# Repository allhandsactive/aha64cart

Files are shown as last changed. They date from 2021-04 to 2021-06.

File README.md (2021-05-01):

## Simple64Cart: AHA Edition ##

This is a modified version of [Simple64Cart](https://github.com/go4retro/Simple64Cart) with the following changes.
* Moved ROM socket slightly to the left so it no longer is pushing up against the board edge
* Allow the use of 16k cart images.
* Allow select one of four 16k banks in the 64k ROM by changing A14 and A15 values via jumpers.

### Jumper Settings ###

##### A14/A15 #####

Jumpers A14 and A15  allow selecting one of four banks in the 64k ROM. This will allow you to program up to four ROM images in an select which one you wish to boot when the computer starts up.

| Memory | A14 | A15 |
| ---|---|---|
|0x0000-0x3fff| closed | closed |
|0x4000-0x7fff| open | closed |
|0x8000-0xbfff| closed | open |
|0xC000-0xffff| open | open |

##### EXROM/GAME #####

These two jumpers /EXROM and /GAME control which memory mapping the C64 uses when mapping your ROM into memory.

There are 3 types of cartridges, 8k, 16k and Ultimax (16k). The two different 16k mappings place the upper 8k at different locations in memory. The main 16k mode will place it at 0xA000 overwriting the basic ROM and Ultimax mode will place it at 0xE000 overwriting the kernel ROM. The lower 8k is always mapped into 0x8000.

The Ultimax mapping is for compatibility with the Japanese Commodore "MAX" computers.

| Mapping | /GAME  | /EXROM |
|---|---|---|
|  None | open | open |
| 8k  (0x8000-0x9 fff) | open | closed |
| 16k (Ultimax) (0x8000-0x9fff),(0xe000-0xffff) | closed | open |
| 16k (0x8000-0x9fff),(0xa000-0xbfff) | closed | closed |

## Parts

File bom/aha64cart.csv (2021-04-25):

Query | Qty | Manufacturer | MPN | Octopart URL | Part Description | Description | Schematic Reference | Total Qty (@ Batch Size: 10) | SKU | Packaging | Unit Price (@ Batch Size: 10) | Notes
CF14JT10K0 | 3 | Stackpole Electronics | CF14JT10K0 | https://octopart.com/cf14jt10k0-stackpole+electronics-19205381 | Res Carbon Film 10K Ohm 5% 0.25W(1/4W) -500ppm/ to 0ppm/ Conformal Coated AXL T/R |  | R1, R2, R3 | 30 | CF14JT10K0CT-ND | Cut Tape | 0.0264
C315C104M5U5TA7301 | 1 | KEMET | C315C104M5U5TA7301 | https://octopart.com/c315c104m5u5ta7301-kemet-20253274 | Cap Ceramic 0.1uF 50V Z5U 20% Radial 2.54mm 85 C T/R |  | C1 | 10 | 399-14010-1-ND | Cut Tape | 0.157
1-2199299-2 | 1 | TE Connectivity | 1-2199299-2 | https://octopart.com/1-2199299-2-te+connectivity-34997809 | 28 Position Dual Wipe Ladder Style DIP IC Socket 0.6" Wide 0.1" Pitch | Intended to work with 27SF512 chip. Paid $1.16/chip via ebay. | U1 | 10 | A120354-ND | Tube | 0.718
68000-402 | 2 | Amphenol ICC / FCI | 68000-402 | https://octopart.com/68000-402-amphenol+icc+%2F+fci-46503223 | Conn Unshrouded Header HDR 2 POS 2.54mm Solder ST Top Entry Thru-Hole BergStik® Bulk |  | A14,A15 | 20 | 609-68000-402-ND | Bulk | 0.119
QPC02SXGN-RC | 3 | Sullins | QPC02SXGN-RC | https://octopart.com/qpc02sxgn-rc-sullins-19878795 | 2 Position 2.54 mm Centerline Single Circuit Open Top Jumper |  | J1, J2, J3 | 30 | S9337-ND | Bag | 0.044
1N4148FS-ND | 2 | ON Semiconductor | 1N4148 | https://octopart.com/1n4148-on+semiconductor-6807167 | 1N4148 Series 500 mW 100 V Max Reverse Voltage 200 mA Small Signal Diode -DO-35 |  | D1, D2 | 20 | 1N4148FS-ND | Bulk | 0.068
67997-404HLF | 1 | Amphenol ICC / FCI | 67997-404HLF | https://octopart.com/67997-404hlf-amphenol+icc+%2F+fci-90333671 | Conn Unshrouded Header HDR 4 POS 2.54mm Solder ST Top Entry Thru-Hole BergStik® Bulk |  | !GAME/!EXROM | 10 | 609-3242-ND | Bag | 0.208

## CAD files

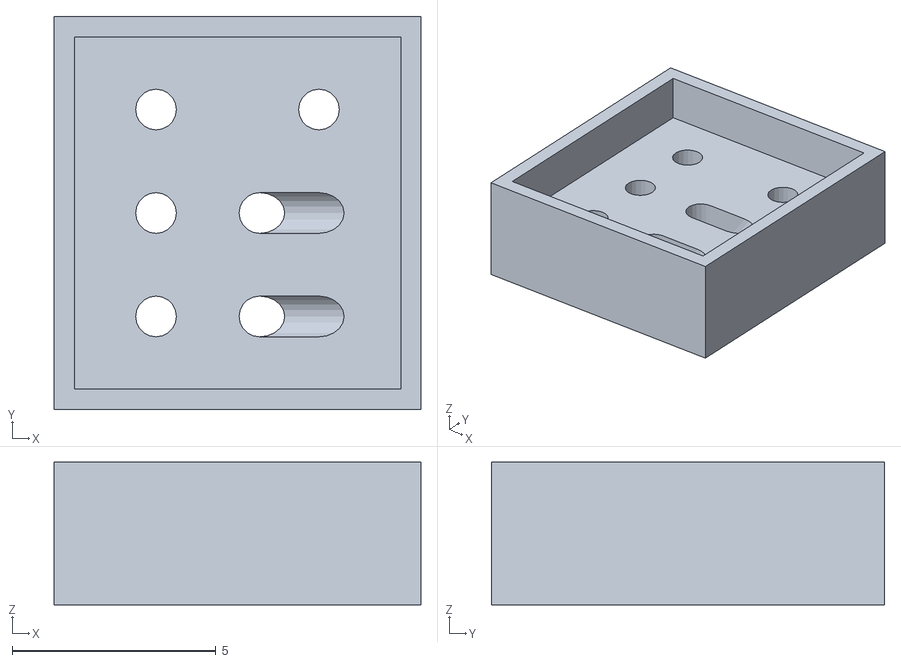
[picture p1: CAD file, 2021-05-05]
case/switch-adapter.stl
9.00 x 9.65 x 3.50

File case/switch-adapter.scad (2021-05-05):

//size of the switch
switch_x = 4;
switch_y = 8.65;
switch_z = 3.7;


//pin spacing on board
hole_x  = 2.54; //change this one
hole_y  = 2.54;


th = 0.5;

rim_h = 1.5;

height = 2;

pin_size = 1;

angle = atan((switch_x - hole_x)/height);
/*
        (switch_x - hole_x)
         _______
     h   |     /
     e   |    /
     i   |   /
     g   |  /
     h   | /
     t   |/
*/


$fn=20;

module switch(){
    //switch body
    cube([switch_x + 0.01, switch_y, switch_z]);
    //slide switch itself
    translate([(switch_x-1.5)/2, (switch_y-3.55)/2, switch_z]) cube([1.5, 3.55, 1.9]);

    //pins
    // translate([switch_x/2, switch_y/2, -4.6]) cylinder(h=5, d=0.5);
    // translate([switch_x/2, switch_y/2 + 2.54, -4.6]) cylinder(h=5, d=0.5);
    // translate([switch_x/2, switch_y/2 - 2.54, -4.6]) cylinder(h=5, d=0.5);
}

module pins(){
    translate([0, 0, -1]) cylinder(h=5, d=pin_size);
    translate([0, hole_y, -1]) cylinder(h=5, d=pin_size);

    //switch 3rd pin
    translate([0, 2.54 + 2.54, -1]) cylinder(h=5, d=pin_size);

    hull() {
        translate([hole_x, 0, 0]) cylinder(h=5, d=pin_size);
        translate([hole_x, 0, 0]) rotate([0, angle, 0]) cylinder(h=5, d=pin_size);
    }
    hull() {
        translate([hole_x, hole_y, 0]) cylinder(h=5, d=pin_size);
        translate([hole_x, hole_y, 0]) rotate([0, angle, 0]) cylinder(h=5, d=pin_size);
    }

    //switch 3rd pin
    hull() {
        // translate([hole_x, 2.54 + 2.54, -1]) cylinder(h=5, d=pin_size);
        translate([switch_x, 2.54 + 2.54, -1]) cylinder(h=5, d=pin_size);
    }
}



difference() {
    translate([-th, -th, 0]) cube([switch_x*2 + 2*th, switch_y + 2*th, height + rim_h]);

    translate([0, 0, height]) switch();
    translate([switch_x, 0, height]) switch();

    //cutout for 3rd pin to bend into
    translate([switch_x/2, switch_y/2 + 2.54, 0]) hull() {
        translate([0, 0, 0.4]) rotate([270, 0, 0]) cylinder(h=20, d=pin_size);
        translate([0, 0, -1]) rotate([270, 0, 0]) cylinder(h=20, d=pin_size);
    }

    //cutout for 3rd pin to bend into
    translate([3*switch_x/2, switch_y/2 + 2.54, 0]) hull() {
        translate([0, 0, 0.4]) rotate([270, 0, 0]) cylinder(h=20, d=pin_size);
        translate([0, 0, -1]) rotate([270, 0, 0]) cylinder(h=20, d=pin_size);
    }

    translate([switch_x/2, switch_y/2 - 2.54, 0]) pins();
}

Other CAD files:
case/c64-cartridge.scad

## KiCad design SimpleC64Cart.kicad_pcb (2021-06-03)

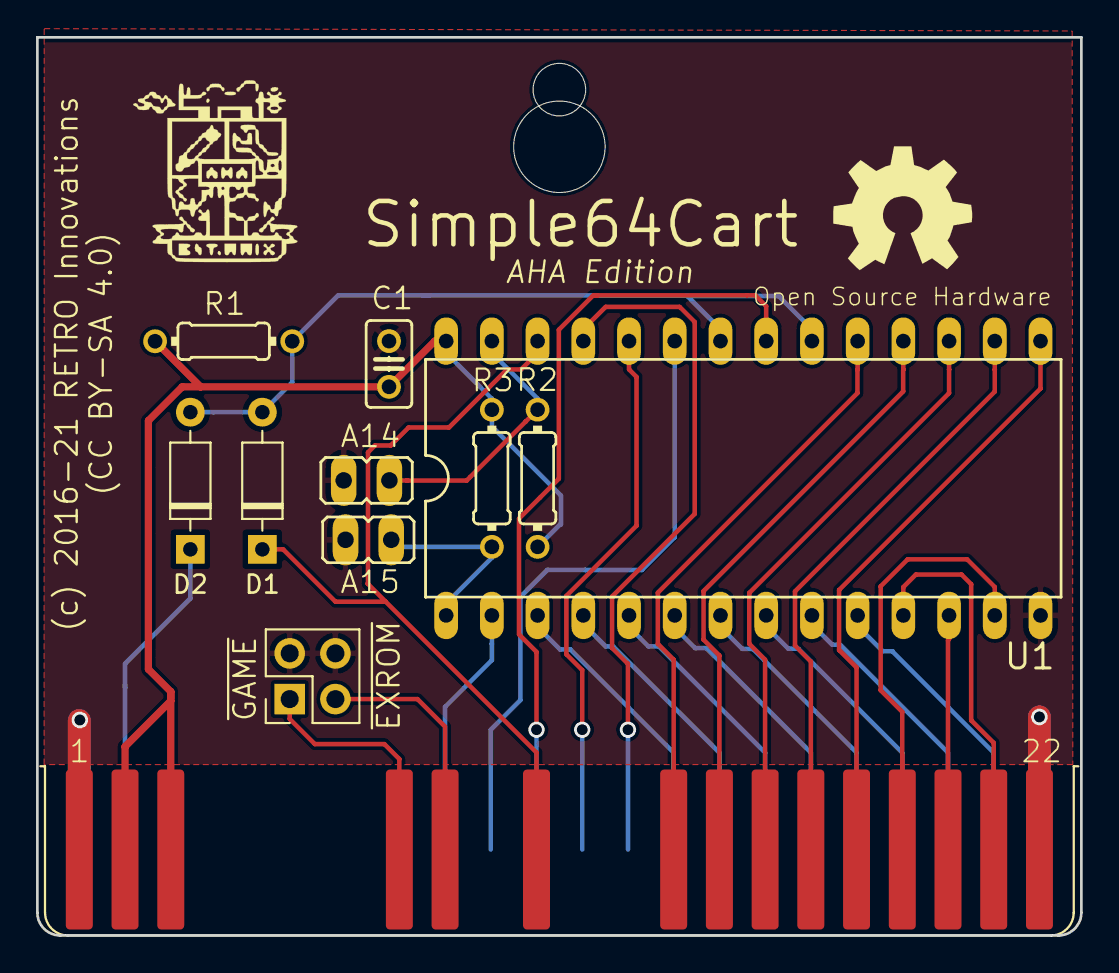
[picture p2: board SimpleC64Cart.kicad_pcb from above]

Board: 2 copper layers, 58.0 x 49.9 mm, 13 parts (0 on the bottom side), 30 nets.

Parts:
A14, A15: Conn_01x02_Male; JP1
C1: 0.1uf; C025-025X050
CART: CARTRIDGE_C64
D1, D2: D_Small; D_DO-35_SOD27_P7.62mm_Horizontal
GOLD_ORB_SM1: Open Source Hardware; OSHW_8MM
J1: TYPE; PinHeader_2x02_P2.54mm_Vertical
R1, R2, R3: 10k; 0204_7
U1: 27512G; DIL28-6
X1: EXPANSION_PORT_C64_EDGE; MA100-22-2

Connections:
/A0: U1.10, X1.Y
/A1: U1.9, X1.X
/A2: U1.8, X1.W
/A3: U1.7, X1.V
/A4: U1.6, X1.U
/A5: U1.5, X1.T
/A6: U1.4, X1.S
/A7: U1.3, X1.R
/A8: U1.25, X1.P
/A9: U1.24, X1.N
/A10: U1.21, X1.M
/A11: U1.23, X1.L
/A12: U1.2, X1.K
/D0: U1.11, X1.21
/D1: U1.12, X1.20
/D2: U1.13, X1.19
/D3: U1.15, X1.18
/D4: U1.16, X1.17
/D5: U1.17, X1.16
/D6: U1.18, X1.15
/D7: U1.19, X1.14
/~EXROM: J1.3, X1.9
/~GAME: J1.1, X1.8
/~ROMH: D2.1, X1.B
/~ROML: D1.1, U1.26, X1.11
GND: A14.1, A15.1, C1.2, J1.2, J1.4, U1.14, X1.1, X1.22, X1.A, X1.Z
unnamed: A14.2, R2.2, U1.27
unnamed: A15.2, R3.2, U1.1
unnamed: D1.2, D2.2, R1.2, U1.20, U1.22
VCC: C1.1, R1.1, R2.1, R3.1, U1.28, X1.2, X1.3

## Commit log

2021-04-24 Lengthen board by 1 mm
    [SimpleC64Cart.kicad_pcb]
2021-04-24 Add generated gerber files
    [SimpleC64Cart-B.Mask.gbr, SimpleC64Cart-B.Paste.gbr, SimpleC64Cart-B.SilkS.gbr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]
2021-04-25 Modified pcb layout.
    * support 16k rom images
    * jumpers allow using 1 of 4 16k banks
    [SimpleC64Cart.kicad_pcb]
2021-04-25 Update gerbers
    [SimpleC64Cart-B.Mask.gbr, SimpleC64Cart-B.Paste.gbr, SimpleC64Cart-B.SilkS.gbr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]
2021-04-25 Add BOM Files
    [aha64cart.csv, aha64cart.ods]
2021-05-04 added unmodified c64 cart from thingiverse, and added a switch adapter to use switches instead of jumpers
    [c64-cartridge.scad, switch-adapter.scad, switch-adapter.stl]
2021-05-05 updated switch adapter dimensions
    [switch-adapter.scad, switch-adapter.stl]
2021-06-03 Add schematic for board layout
    [SimpleC64Cart.kicad_pcb, SimpleC64Cart.sch]

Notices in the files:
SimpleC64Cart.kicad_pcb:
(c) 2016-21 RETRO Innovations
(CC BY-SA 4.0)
